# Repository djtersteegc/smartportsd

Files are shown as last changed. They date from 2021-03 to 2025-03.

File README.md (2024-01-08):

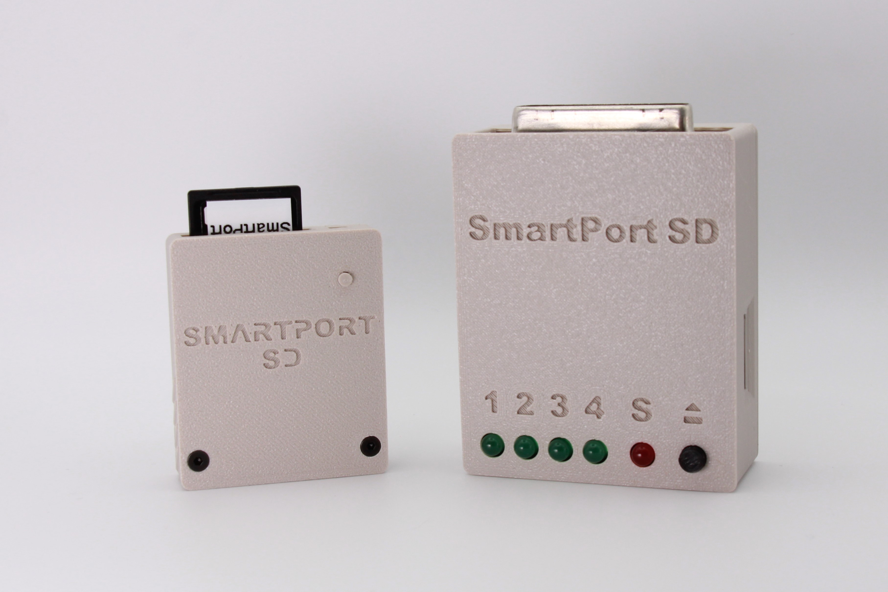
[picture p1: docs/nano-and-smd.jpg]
nano-and-smd


A couple PCB's I've designed to run the SmartportSD FAT code from Katherine Stark (based on the work of Robert Justice and Andrea Ottaviani) allowing you to connect a 32MB ProDOS partition to your SmartPort enabled Apple II (IIc, IIc+, IIgs). If you have a Apple IIe, solutions like a SoftSP card with you Disk II card, or something like Brad Bell's [SmartDiskII](https://github.com/btb/SmartDiskII) card will also allow hookup and usage. Yes, it works with Total Replay.

# SmartportSD Nano Shield

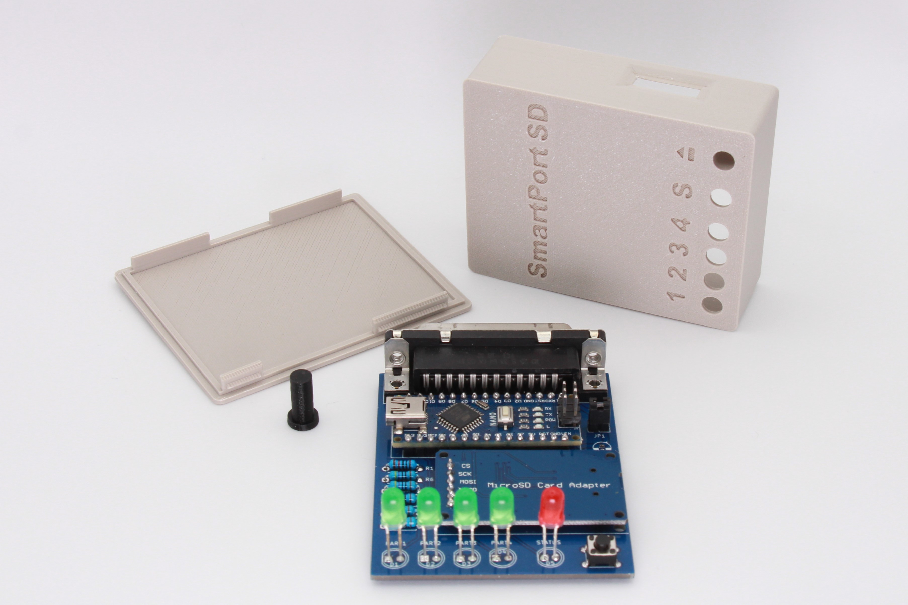
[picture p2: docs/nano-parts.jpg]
nano-parts


This is my original design.  Works best with a Duo Disk cable, but has a header to wire up a custom cable if needed.  All through hold modules, super easy build. I added some additional LED's to indicate which of the four ProDOS partitions is currently loaded.

See the [Nano Shield page](smartportsd-nano-shield/README.md) for BOM and assembly instructions.

# SmartportSD SMD

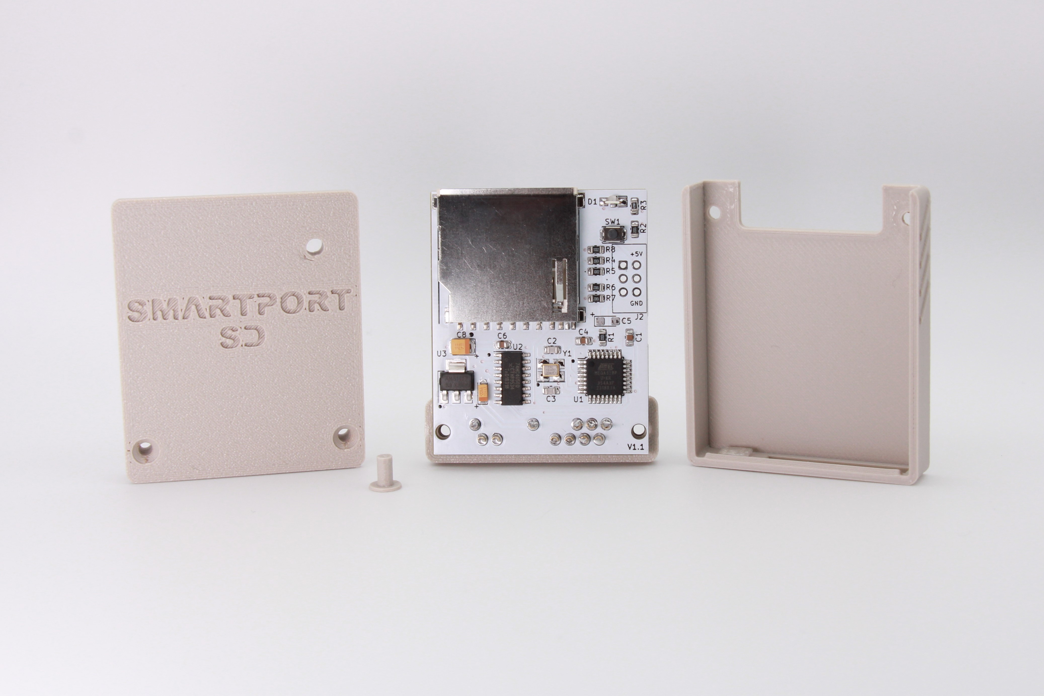
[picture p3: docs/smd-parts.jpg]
smd-parts


This one is a bit more of an advanced build and is based off my [Tapecart SD](https://github.com/djtersteegc/tapecart-sd-vertical) design I did for the Commodore 64. Uses a full size SD card for ease of handling and plugs in directly to the back of an Apple IIc/c+/gs.  There is a lightpipe for the activity LED and the narrow case design allows plenty of clearance for the bulkiest composite video connectors I could find in my collection.

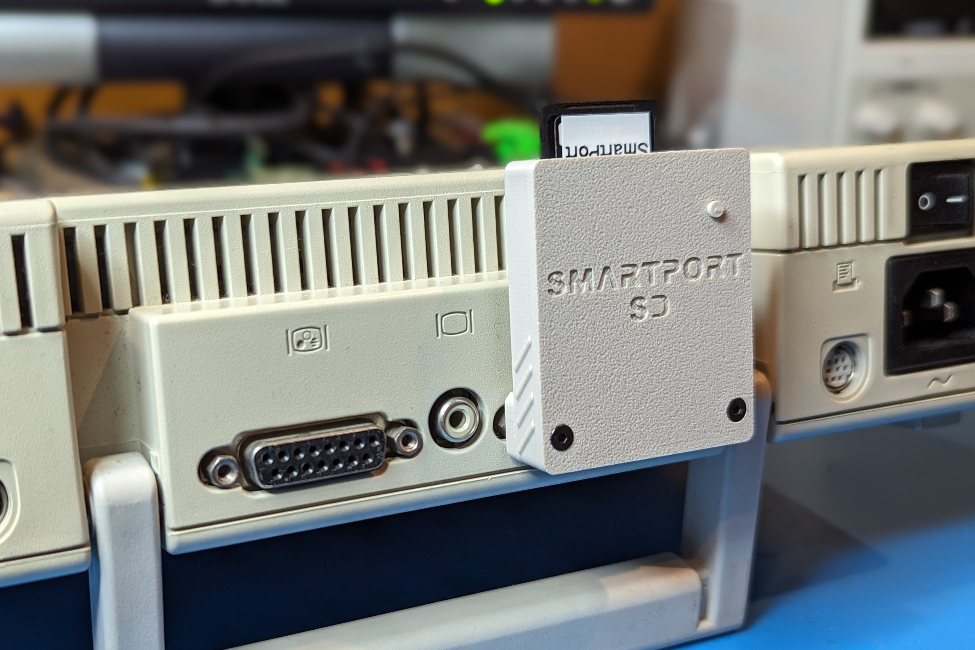
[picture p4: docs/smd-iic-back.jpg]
smd-iic-back


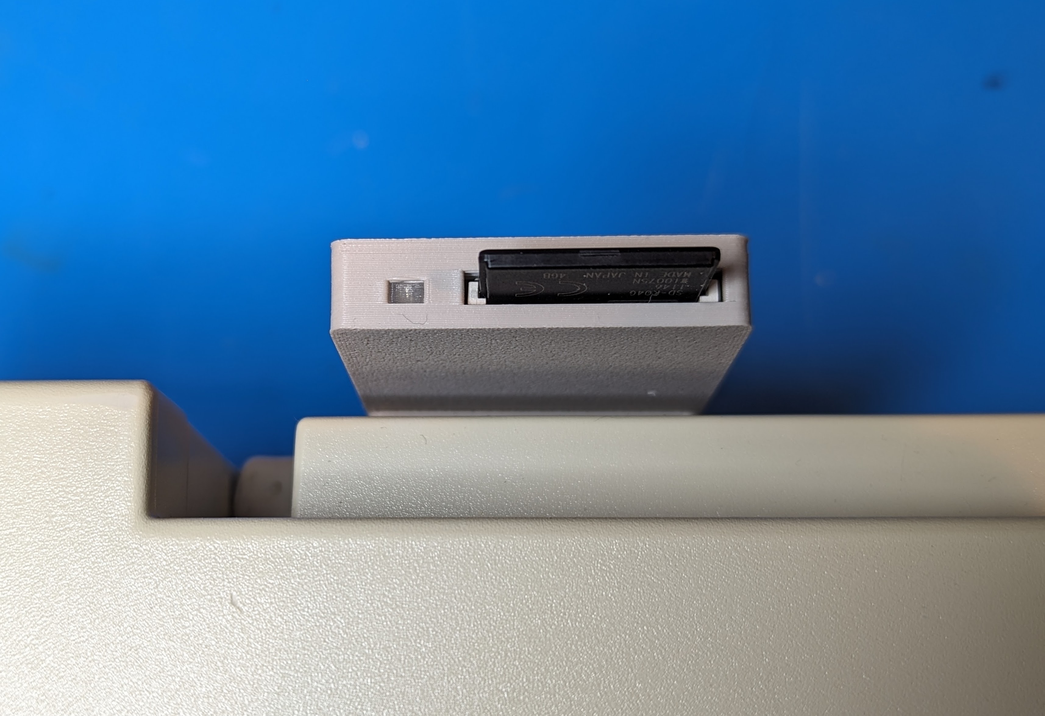
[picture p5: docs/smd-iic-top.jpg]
smd-iic-top


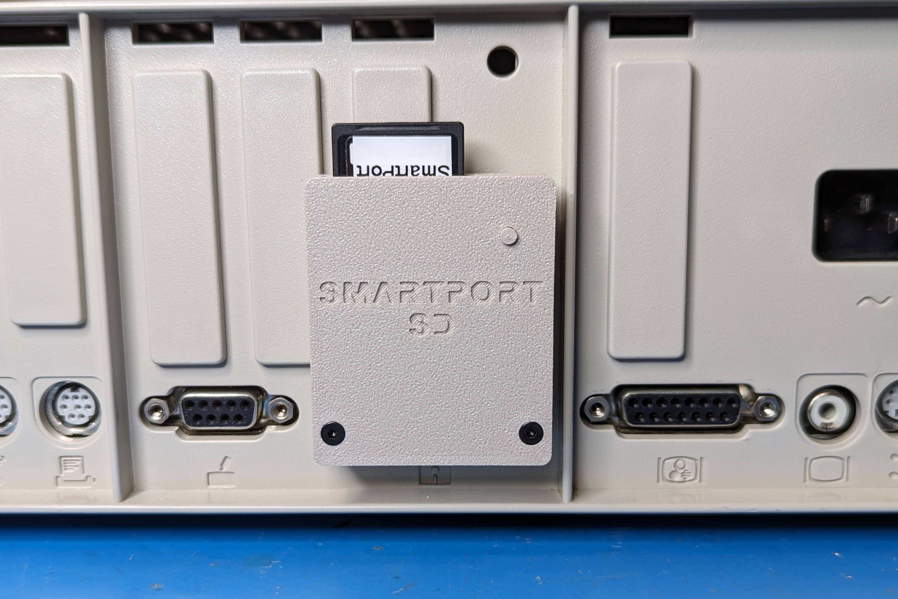
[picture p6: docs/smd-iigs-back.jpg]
smd-iigs-back


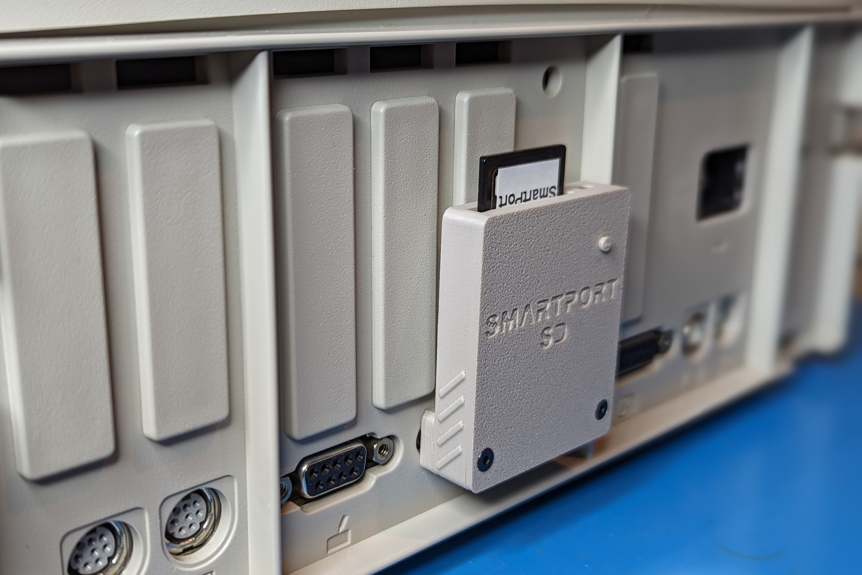
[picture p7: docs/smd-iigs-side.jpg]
smd-iigs-side


See the [SMD page](smartport-smd/README.md) for BOM and assembly instructions.

# Getting a Board

If I have extra PCB's, they will be listed on Tindie.

https://www.tindie.com/products/tersteeg/smartportsd-apple-ii-pcb/

Otherwise, you can download the gerbers and use your favorite fab (JLCPCB, PCBWay, etc.) to make your own batch.

# Acknowledgements

Robert Justice for his original SmartPortCFA project http://www.users.on.net/~rjustice/SmartportCFA/SmartportCFA.htm

Andrea Ottaviani for his Arduino/SD port of Robert's work http://www.users.on.net/~rjustice/SmartportCFA/SmartportSD.htm

Katherine Stark for adding FAT support to Andrea's work to make it easier to manage the partitions on the SD card. https://gitlab.com/nyankat/smartportsd

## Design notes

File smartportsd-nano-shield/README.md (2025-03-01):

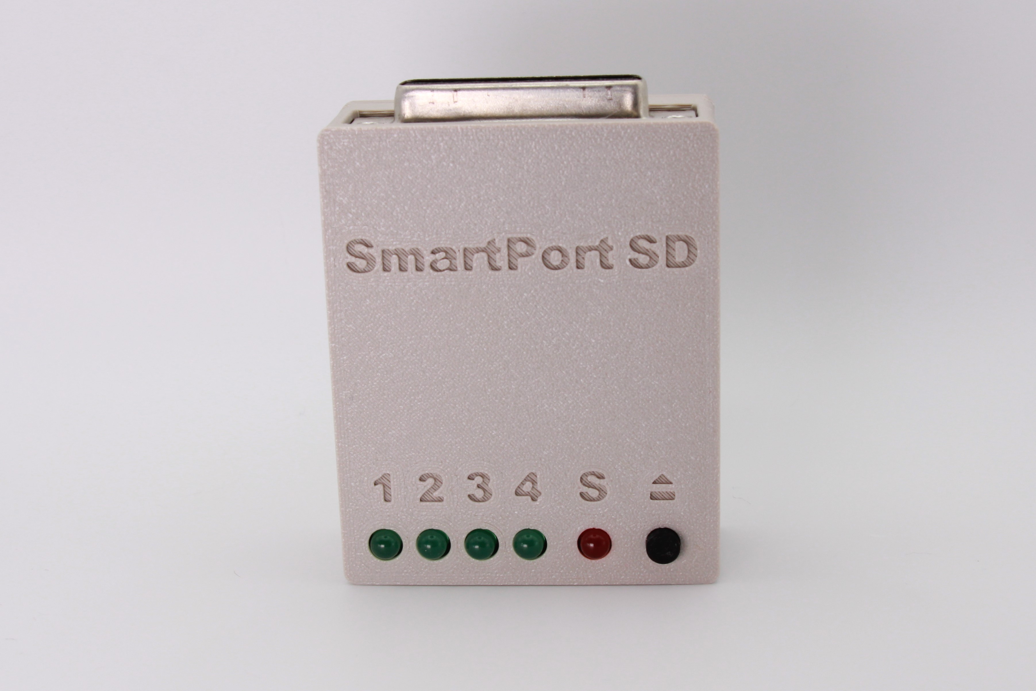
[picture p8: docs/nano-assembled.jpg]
nano-assembled


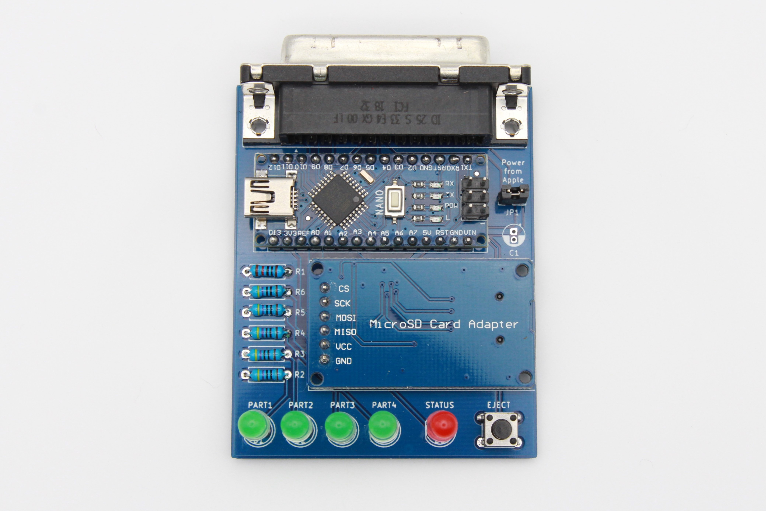
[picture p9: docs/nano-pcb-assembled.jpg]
nano-pcb-assembled


# BOM

All components can be sourced from the usual low-cost China based vendors for a total build cost of around $10. An interactive BOM and parts placement diagram is available.

[Interactive Bill of Materials (BOM)](https://djtersteegc.github.io/smartportsd/ibom-nano-shield-v1.0.html)

### Arduino Nano v3.0

I've had good luck with the ~$2 Chinese clones, but I would suggest flashing it first before soldering to the board.  Sometimes you do get a bad unit, or a unit that hasn't been flashed with the boot loader and requires you flash it yourself via the ICSP headers.

Make sure it's a 16Mhz ATMEGA328P board running at 5V.

### Micro SD Card Connector

This is the common push-push [Micro SD module](https://www.aliexpress.com/item/1873549637.html) with level shifters.  Sometimes it may say "Catalex" (maybe the original designer?) on the back of the PCB.  You will need to remove the pre-soldered right-angle header they all seem to come with so you can mount it upside down on the shield board.

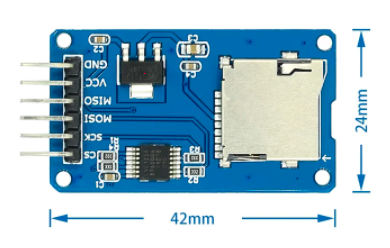
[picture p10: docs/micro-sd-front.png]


### Bulk Capacitor

C1 is a bulk storage capacitor for the 5V rail.  It is optional since the Arduino already has caps on-board, but if you have a marginal SmartPort 5V line or experience other power issues, they could help stabilize the overall board.  Any value between 10uf to 47uf is fine.

### Resistors

Either 1/4W or 1/8W can be used in all locations.

R1 is the pull-down resistor for the eject button.  Anything from 10K to 47K is probably fine here.

R2 through R6 controls the activity and active partition LED brightness. A good calculator is at:

[http://ledcalc.com/](http://ledcalc.com/)

if you want to use something other the 470 ohm spec on the board.  Just don't exceed 20ma.

# Case

STL's and the [DesignSpark Mechanical](https://www.rs-online.com/designspark/mechanical-software) source file for an simple snap fit enclosure are in the **enclosure** directory. Clearances are intentionally a bit tight so nothing rattles, but it prints well on a standard Ender 3 type printer without any post processing needed.

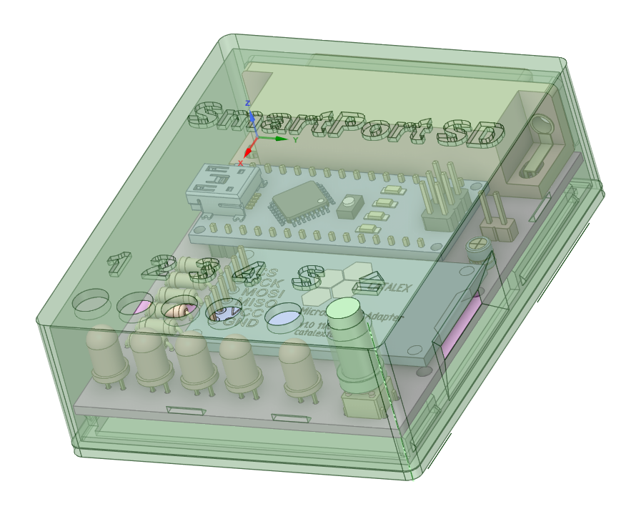
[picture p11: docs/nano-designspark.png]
nano-designspark


# Assembly

If you plan on casing the PCB, print the case out first before the install the LED's you can space them properly.  I use about 2.4mm of reveal with standard 5mm LED's so they are just poking above the surface of the case face.

# Firmware Flashing

Katherine's original repo is at https://gitlab.com/nyankat/smartportsd

I have a fork at https://gitlab.com/tersteeg/smartportsd that adds support for the four LED's in this design that show you the currently active partition.

# Connecting to your Apple II

You have two options here.  If you are lucky enough to have a DB19 to DB25 DuoDisk Drive cable, you can simply solder on a female DB25 jack and you're good to go.

The IDC-20 pin mapping can be used with the various DB19 to IDC-20 adapter available, like the one from the Fujinet project, https://github.com/FujiNetWIFI/fujinet-hardware/tree/master/AppleII/DB-19M-Adapter-Male-Rev1

Or you can wire up your own cable using the 2.54mm 9p header J2. The pinout is as follows:

| SmartPort | DB19 pin | IDC-20 pin | J2 pin | DB25 pin |
| --- | --- | --- | --- | --- |
| RDDATA | 18 | 16 | 1 | 3 |
| PH0 | 11 | 2 | 2 | 15 |
| PH1 | 12 | 4 | 3 | 16 |
| PH2 | 13 | 6 | 4 | 17 |
| PH3 | 14 | 8 | 5 | 18 |
| WRDATA | 19 | 18 | 6 | 6 |
| +5V | 6 | 11 | 7 | 7 |
| GND | 1 | 1 | 8 | 2 |
| WRPROT | 10 | 20 | 9 | 12 |

# Usage

If you wish to power your board from the 5V SmartPort line, simply install and close jumper JP1.  Be warned there is no protection on the board from back feeding voltage into the Apple host computer if you also power the Arduino via the USB connector, so only close this jumper when not using another power source on the Arduino.

# Getting a Board

If I have extra PCB's, they will be listed on Tindie.

https://www.tindie.com/products/tersteeg/smartportsd-apple-ii-pcb/

Otherwise you can download the Gerbers and use your favorite fab (JLCPCB, PCBWay, etc.) to make your own batch.  It's a standard two layer, 1oz copper board with dimensions of 70mm x 56mm.

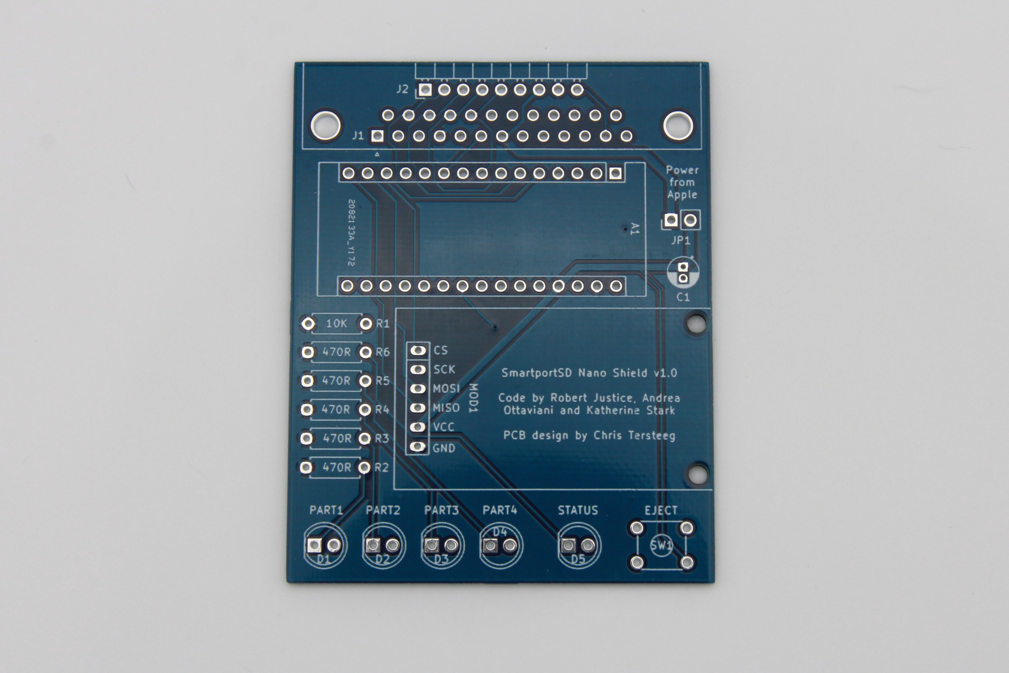
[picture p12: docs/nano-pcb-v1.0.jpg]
nano-pcb-v1.0


# Hardware Revisions

### Version 1.0

Tested and working.

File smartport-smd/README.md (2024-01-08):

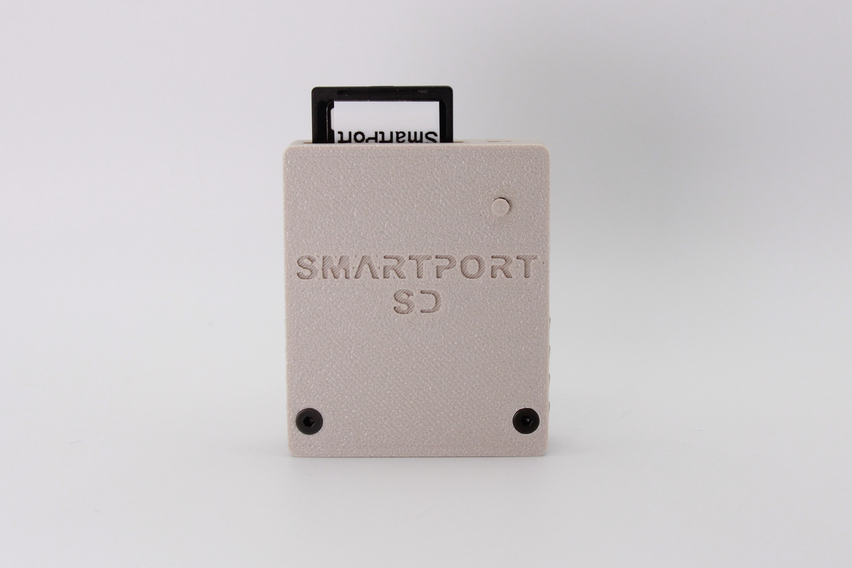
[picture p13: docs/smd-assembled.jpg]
smd-assembled


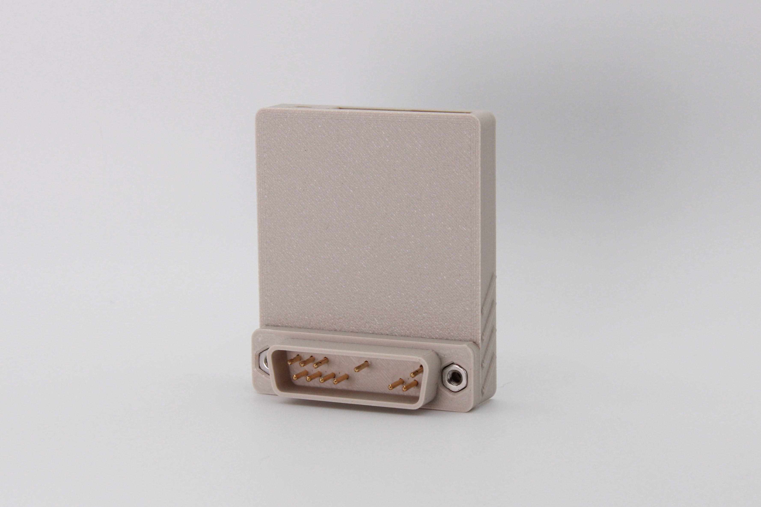
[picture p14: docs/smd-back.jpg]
smd-back


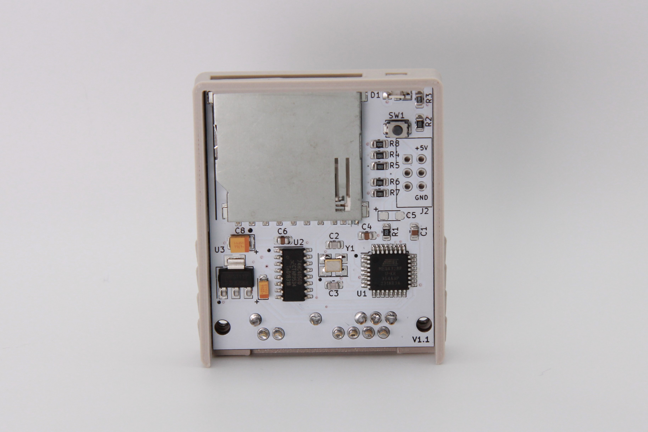
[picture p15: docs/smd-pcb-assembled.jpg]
smd-pcb-assembled


# BOM

There's an interactive BOM [here](https://djtersteegc.github.io/smartportsd/ibom-smd-v1.1.html), and CSV version with footprint info [here](https://djtersteegc.github.io/smartportsd/bom-smd-v1.1.csv). The interactive one is super useful when placing the SMD components.

C5 is an optional bulk capacitor for the 5V power rail near the MCU.  In my experience building these it is not needed.

The SD card connector is commonly available from several different Chinese suppliers and often called "long body", "non popping", or "push pull" on AliExpress or eBay.

https://www.aliexpress.us/item/3256805779248826.html

Here's some links on LCSC.

https://www.lcsc.com/product-detail/SD-Card-Connectors_Hanbo-Electronic-SD-112_C961673.html

https://www.lcsc.com/product-detail/SD-Card-Connectors_XUNPU-SD-102_C266602.html

https://www.lcsc.com/product-detail/SD-Card-Connectors_Megastar-ZX-SD-282-8Y_C7419835.html

It should also cross with a Wurth 693063010911 or AMP GSD090012SEU if you want something domestically.

The pins for the DB19 connector can be purchased from this seller on AliExpress,  https://www.aliexpress.us/item/3256802431271655.html Ideally I would have used the "PCB Plug" model if they stocked them which are similar to the TE/AMP 5-745287-4 model mozzwald used on the [FujiApple DB19 to IDC20 adapters](https://github.com/FujiNetWIFI/fujinet-hardware/tree/master/AppleII/DB-19M-Adapter), but these are much more cost effective and work just as well once assembled.

# Case

The case was created in DesignSpark and the design file is available if you would like to modify it further.

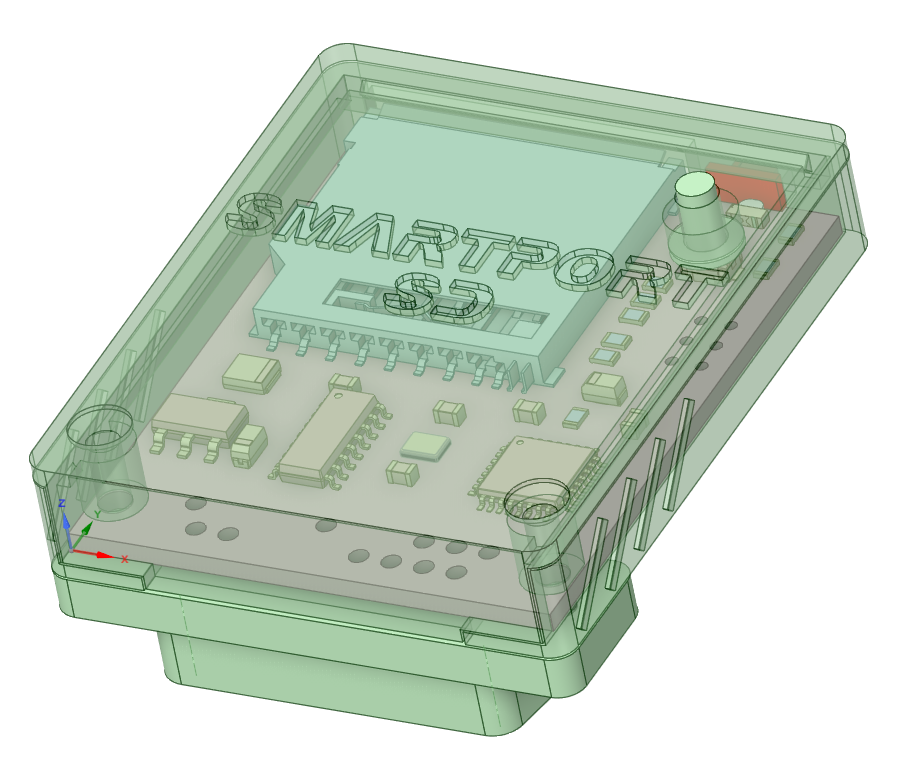
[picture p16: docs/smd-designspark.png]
smd-designspark


There is a single light pipe that should be printed in transparent material, or you can just leave it off completely. The case is designed to be printed at 0.2mm layer heights and assembled with two M2.5x14mm screws through the connector body and two M2.5 nuts pushed into either the handle or lid.

# Assembly

Assemble all the SMD components.  I use solder paste hand applied with a pneumatic dispenser and then finish on a hot plate. But you can also hand solder, use hot air, or even order a stencil for paste application and use a proper reflow oven. I use a red LED for the activity indicator. Make sure to observe polarity with the green stripe on the LED to the right matching the white stripe on the PCB silkscreen.

For the ATMEGA328P chip I did use part of stencil I had from a previous project with the same footprint, or you can buy one from [Amazon](https://www.amazon.com/Proto-Advantage-PA0091-S-TQFP-32-LQFP-32-Stainless/dp/B09886QDY9/ref=sr_1_3). Cheaper than ordering a whole stencil from somewhere like JLCPCB once you factor in shipping costs.

Do NOT install the 2x3 ICSP pin header at J2.  I would recommend flashing the firmware at this point to do basic checks since it's easier to do board rework before you install the DB19 pins.

To install the connector, first take your printed DB19 shell and use a 1.0mm and 2.0mm drill bit to properly size the holes.  I use a cut down DB25 connector to hold the pins straight while soldering. It also makes a nice way to hold everything in a vise.

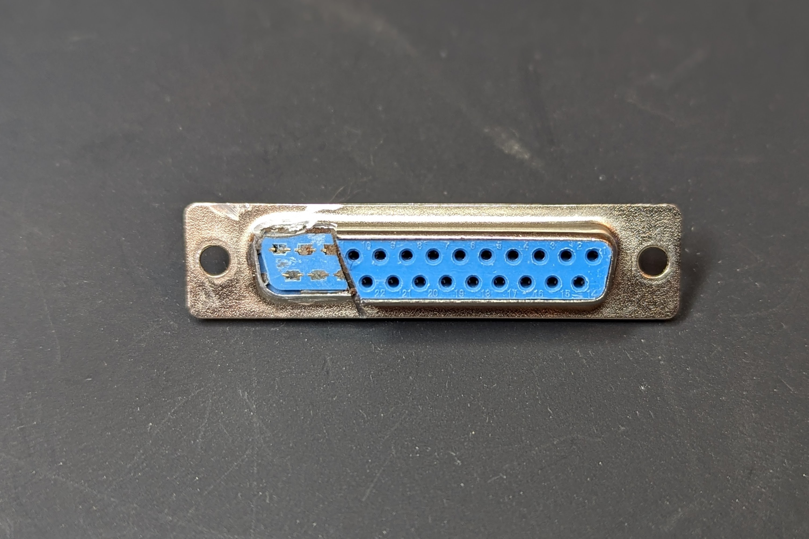
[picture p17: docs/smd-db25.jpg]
smd-db25


Insert the pins and case shell through the case back and assemble with short M2.5 screws.  Tighten the screws gently so you can still slide out the case in the future if needed and then solder the pins. Ensure the tops of all the pins are even and the bottom of the solder cup on the pins should be close to even with the PCB.

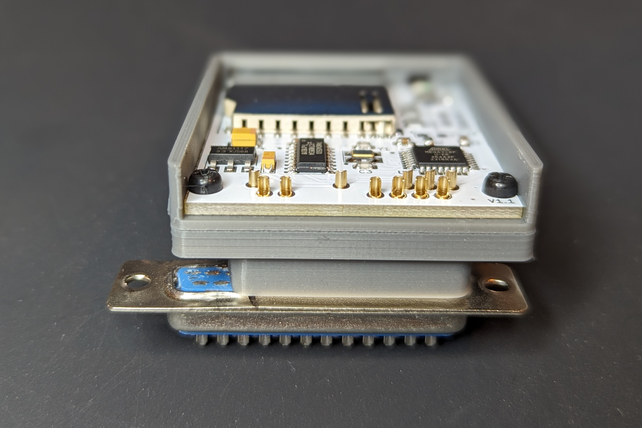
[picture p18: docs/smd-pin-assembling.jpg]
smd-pin-assembling


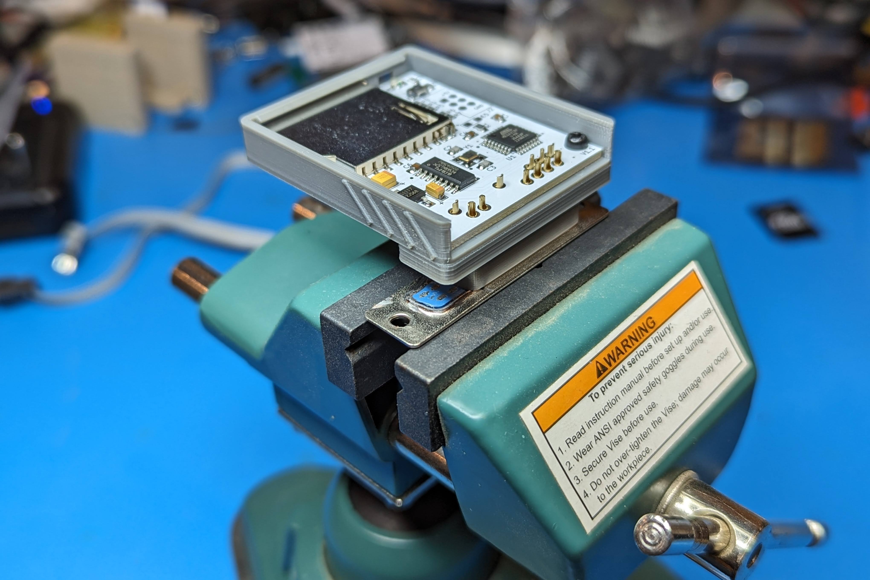
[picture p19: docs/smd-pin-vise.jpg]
smd-pin-vise


When complete it should look something like this when slid out of the case.

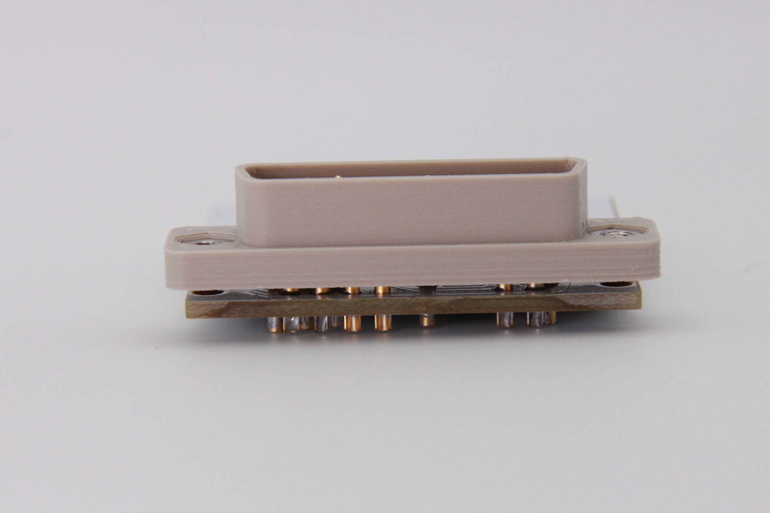
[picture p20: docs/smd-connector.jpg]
smd-connector


Press the light pipe into the LED opening with the lip side facing up and then slide the board in. If you can't slide the PCB under the light pipe, it is installed upside down.  The side mounted LED's should keep the light pipe from falling out, even if it isn't a tight friction fit in the openings.

# Firmware Flashing

The ATmega328P is the same used on an Arduino Uno/Nano/Micro, but lacks the necessary bootloader firmware and serial interfaces to flash via the Arduino IDE or programs like XLoader. You could program the chip before installing it with something like a [TL866/T48](TL866/T48) and a [TQFP32 to DIP 32 adapter](https://www.aliexpress.us/item/2251832227450089.html), but I prefer to just use a cheap [UBSASP](https://www.aliexpress.us/item/2251832600419163.html) and [avrdude](https://github.com/avrdudes/avrdude). Make sure you get a 10 pin to 8 pin adapter with the USBASP if it isn't natively an 8 pin model.

Since you didn't solder the 2x3 pin header on the ICSP port J2, you will need to hold the header pins at an angle in the holes to make contact while you run avrdude.  If you're feeling fancy, you could spring for a [2x3 double row 2.54mm test clip](https://www.aliexpress.us/item/3256805646654844.html) or [handheld pogo pin probe](https://www.aliexpress.us/item/3256805545980544.html).  The cheap angle method works fine for me.

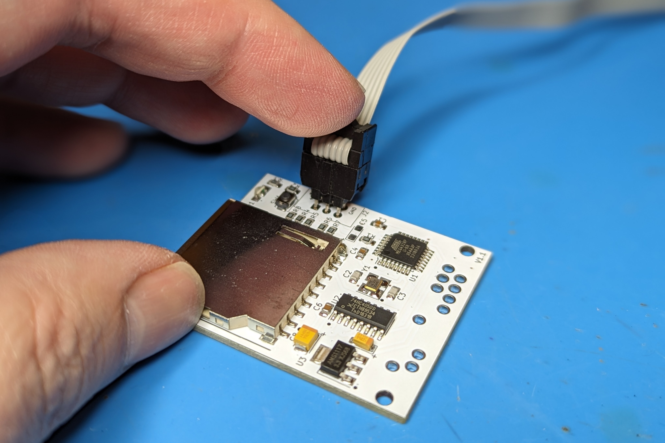
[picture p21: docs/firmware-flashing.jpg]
firmware-flashing


Since this model doesn't have the extra LED's to show the active partition, the firmware used is Katherine's standard version from https://gitlab.com/nyankat/smartportsd.  

In my [firmware](firmware) directory there are couple of Windows scripts and a precompiled version of the SmartportSD firmware.

First you to need to setup your ATMega328p with the correct fuse setting so it uses the external 16 MHz crystal, same as an Arduino board. **burn-328p-fuses.cmd** executes the following:

`avrdude -c usbasp -p m328p -B 125kHz -U lfuse:w:0xFF:m -U hfuse:w:0xDE:m -U efuse:w:0x05:m`

Next flash SmartportSD-1.15.ino.with_bootloader.standard.hex with **flash-smartportsd.cmd** that executes:

`avrdude -c usbasp -p m328p -u -U flash:w:SmartportSD-1.15.ino.with_bootloader.standard.hex`

Plug into your Apple II and enjoy! 

# Getting a Board

If you are in the US, PCB's are available from my Tindie store, https://www.tindie.com/products/tersteeg/smartportsd-apple-ii-pcb/

Otherwise, you can grab the [gerbers](gerbers) and order from your favorite PCB fab.

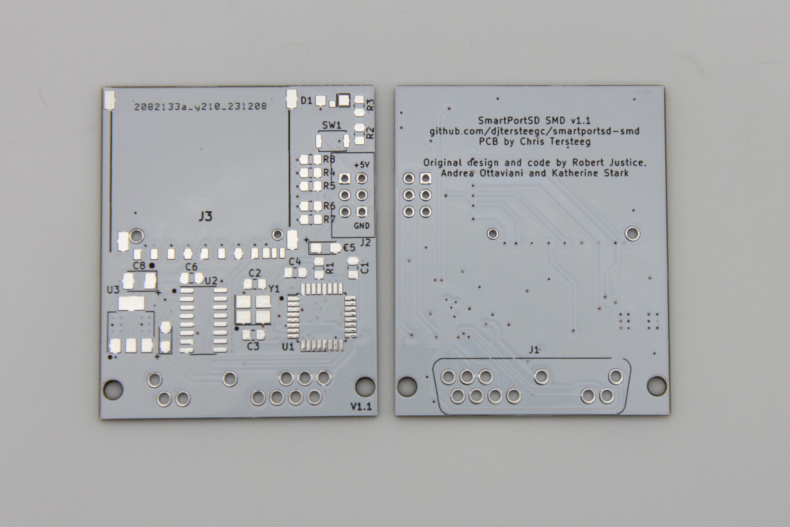
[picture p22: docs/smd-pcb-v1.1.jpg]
smd-pcb-v1.1


# PCB Revisions

### Version 1.0

Worked but since it was pertty much a 1:1 copy of my TapecartSD base PCB, was just a little to wide to clear the composite video connector on an Apple IIc once cased.

### Versions 1.1 (Current)

Board was narrowed to allow needed clearance on IIc/c+ models.

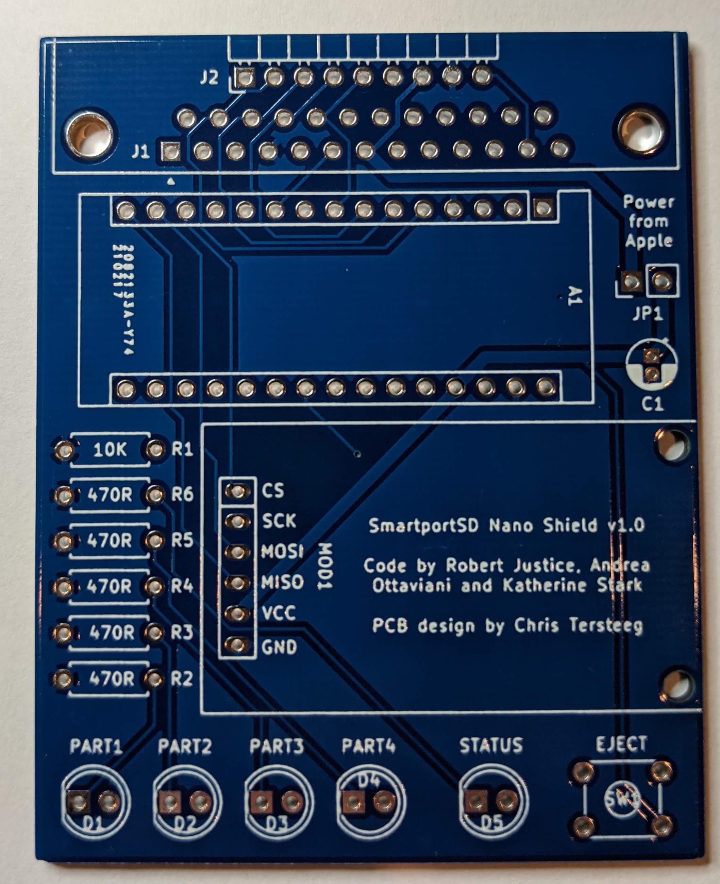
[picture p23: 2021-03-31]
docs/pcb-v1.0.jpg

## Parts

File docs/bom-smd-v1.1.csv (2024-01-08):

# | Reference | Qty | Value | Footprint | DNP
1 | C1, C4, C6 | 3 | 0.1uf | Capacitor_SMD:C_0805_2012Metric_Pad1.18x1.45mm_HandSolder
2 | C2, C3 | 2 | 18pf | Capacitor_SMD:C_0805_2012Metric_Pad1.18x1.45mm_HandSolder
3 | C5, C7 | 2 | 22uf 10V | Capacitor_Tantalum_SMD:CP_EIA-3216-18_Kemet-A_Pad1.58x1.35mm_HandSolder
4 | C8 | 1 | 47uf 10V | Capacitor_Tantalum_SMD:CP_EIA-3528-12_Kemet-T_Pad1.50x2.35mm_HandSolder
5 | D1 | 1 | LED | Tersteeg:1204 Side Emitting LED
6 | J1 | 1 | DB19_Plug | Tersteeg:DSUB-19_Male_Vertical_P2.77x2.84mm_Narrow_MountingHoles
7 | J2 | 1 | ICSP | Connector_IDC:IDC-Header_2x03_P2.54mm_Vertical
8 | J3 | 1 | SD_Card_Push_Pull | TE SD Card 2041021-3:2041021-3_2
9 | R1, R2, R4, R5, R6, R7, R8 | 7 | 10K | Resistor_SMD:R_0805_2012Metric_Pad1.20x1.40mm_HandSolder
10 | R3 | 1 | 470R | Resistor_SMD:R_0805_2012Metric_Pad1.20x1.40mm_HandSolder
11 | SW1 | 1 | SW_SPST | Button_Switch_SMD:SW_Push_SPST_NO_Alps_SKRK
12 | U1 | 1 | ATmega328P-A | Package_QFP:TQFP-32_7x7mm_P0.8mm
13 | U2 | 1 | 4050 | Package_SO:SOIC-16_3.9x9.9mm_P1.27mm
14 | U3 | 1 | AMS1117-3.3 | Package_TO_SOT_SMD:SOT-223-3_TabPin2
15 | Y1 | 1 | 16MHz | Crystal:Crystal_SMD_3225-4Pin_3.2x2.5mm_HandSoldering

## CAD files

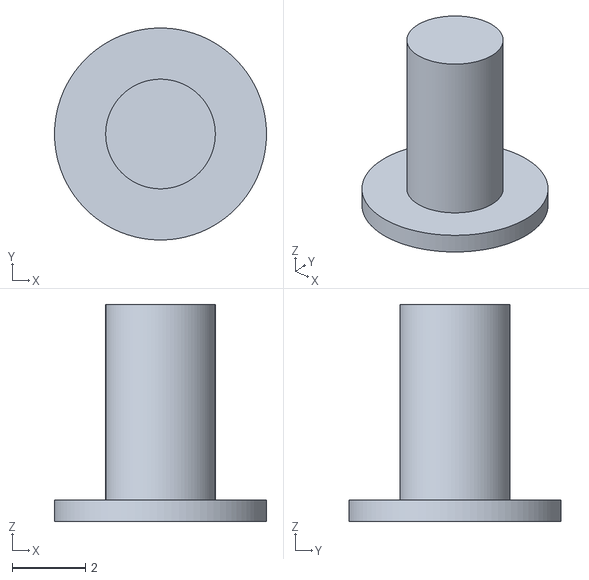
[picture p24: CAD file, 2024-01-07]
smartport-smd/3D/STL/smartport-smd-button.stl
5.80 x 5.80 x 5.95

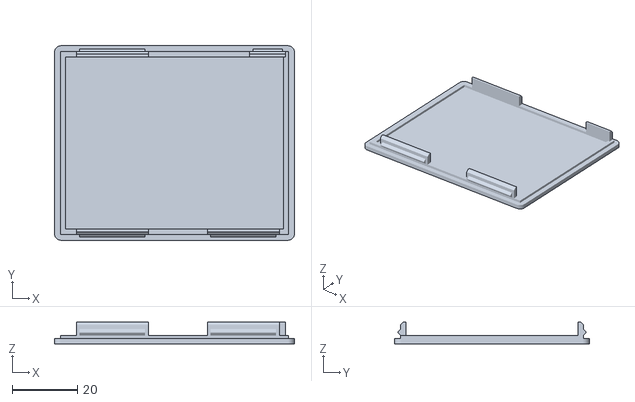
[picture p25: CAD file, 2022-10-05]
smartportsd-nano-shield/enclosure/smartportsd-nano-shield-lid.stl
73.5 x 59.6 x 6.60

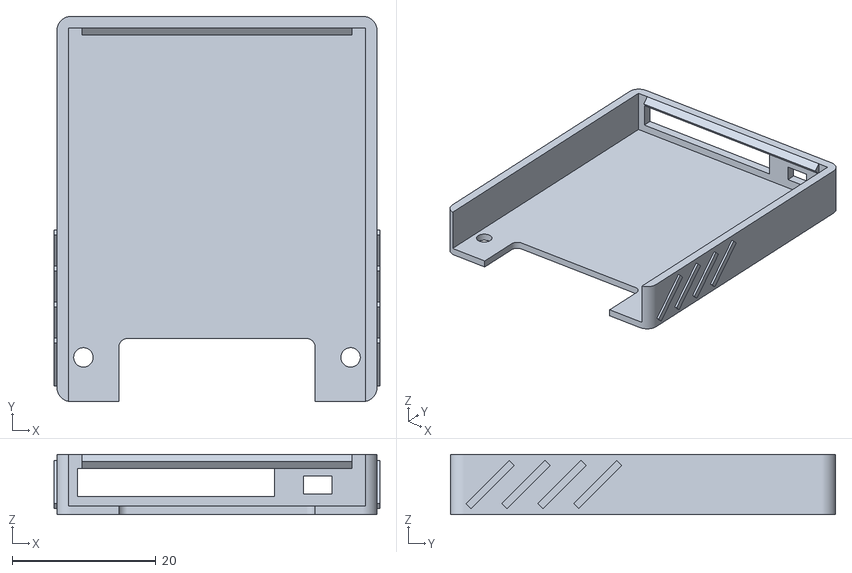
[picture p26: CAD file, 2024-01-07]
smartport-smd/3D/STL/smartport-smd-body.stl
45.4 x 53.6 x 8.40

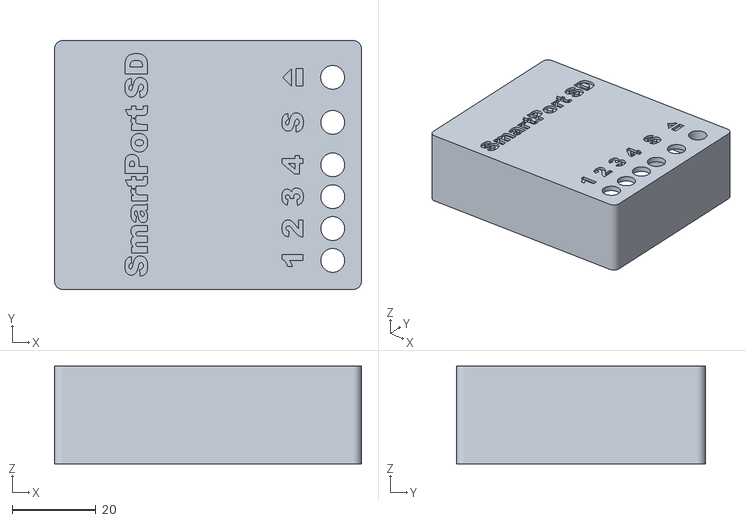
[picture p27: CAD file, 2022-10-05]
smartportsd-nano-shield/enclosure/smartportsd-nano-shield-body.stl
73.5 x 59.6 x 23.4

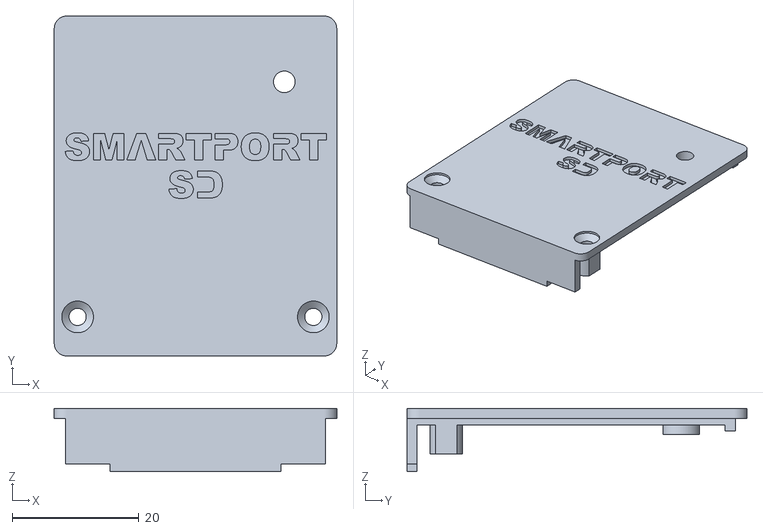
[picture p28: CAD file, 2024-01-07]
smartport-smd/3D/STL/smartport-smd-lid.stl
44.6 x 53.6 x 10.0

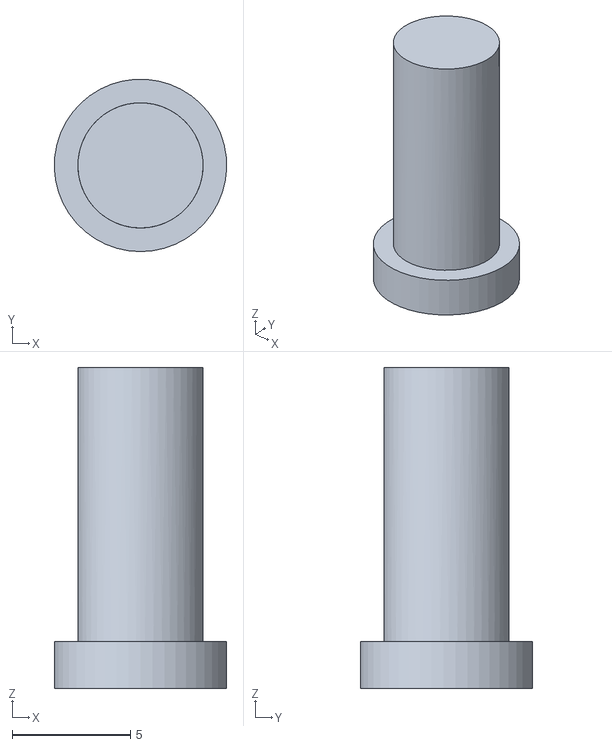
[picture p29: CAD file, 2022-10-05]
smartportsd-nano-shield/enclosure/smartportsd-nano-shield-button.stl
7.30 x 7.29 x 13.6

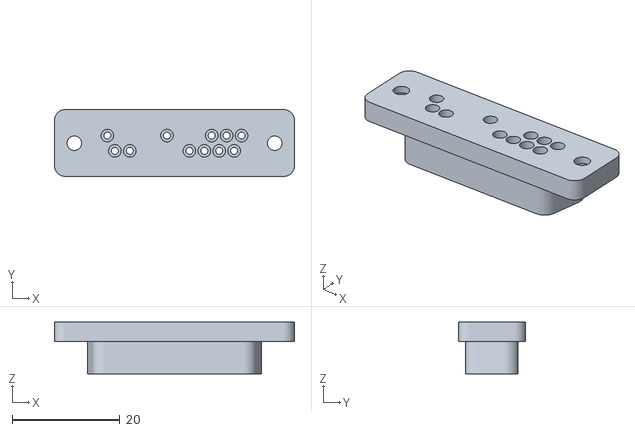
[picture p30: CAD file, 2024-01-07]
smartport-smd/3D/STL/smartport-smd-db19.stl
44.6 x 12.4 x 9.60

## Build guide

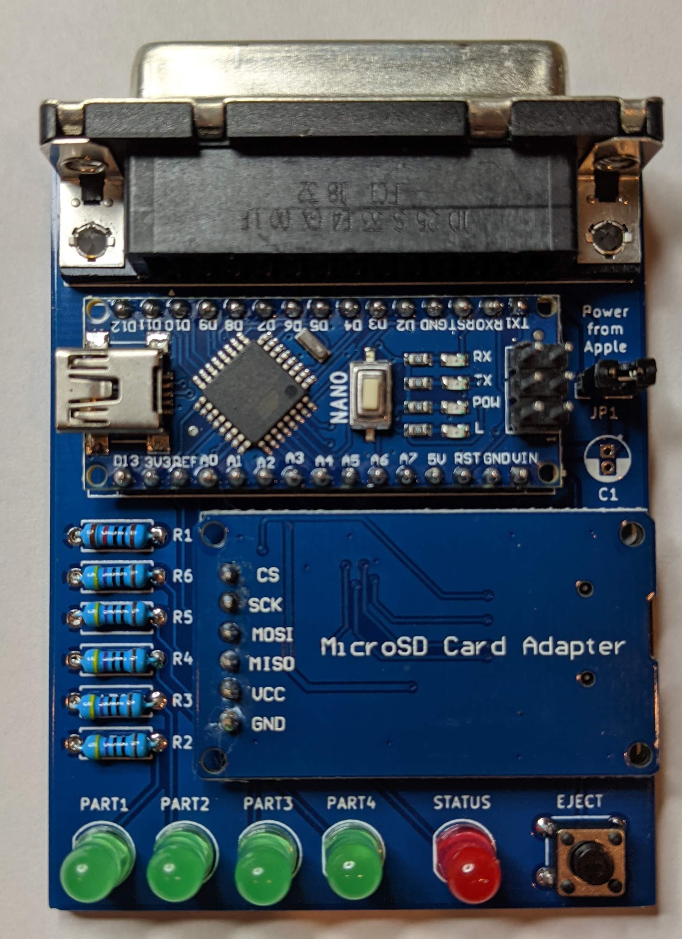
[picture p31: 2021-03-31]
docs/assembled.jpg

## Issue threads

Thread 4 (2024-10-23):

Doesn't seem to build using the latest version of the sdfat arudino library

Monsjakon, 2024-10-23:

hexbus, 2025-02-27:
Yep, you need to backlevel it per here:  https://tinkerdifferent.com/threads/smartportsd-lets-build-it.454/post-34114

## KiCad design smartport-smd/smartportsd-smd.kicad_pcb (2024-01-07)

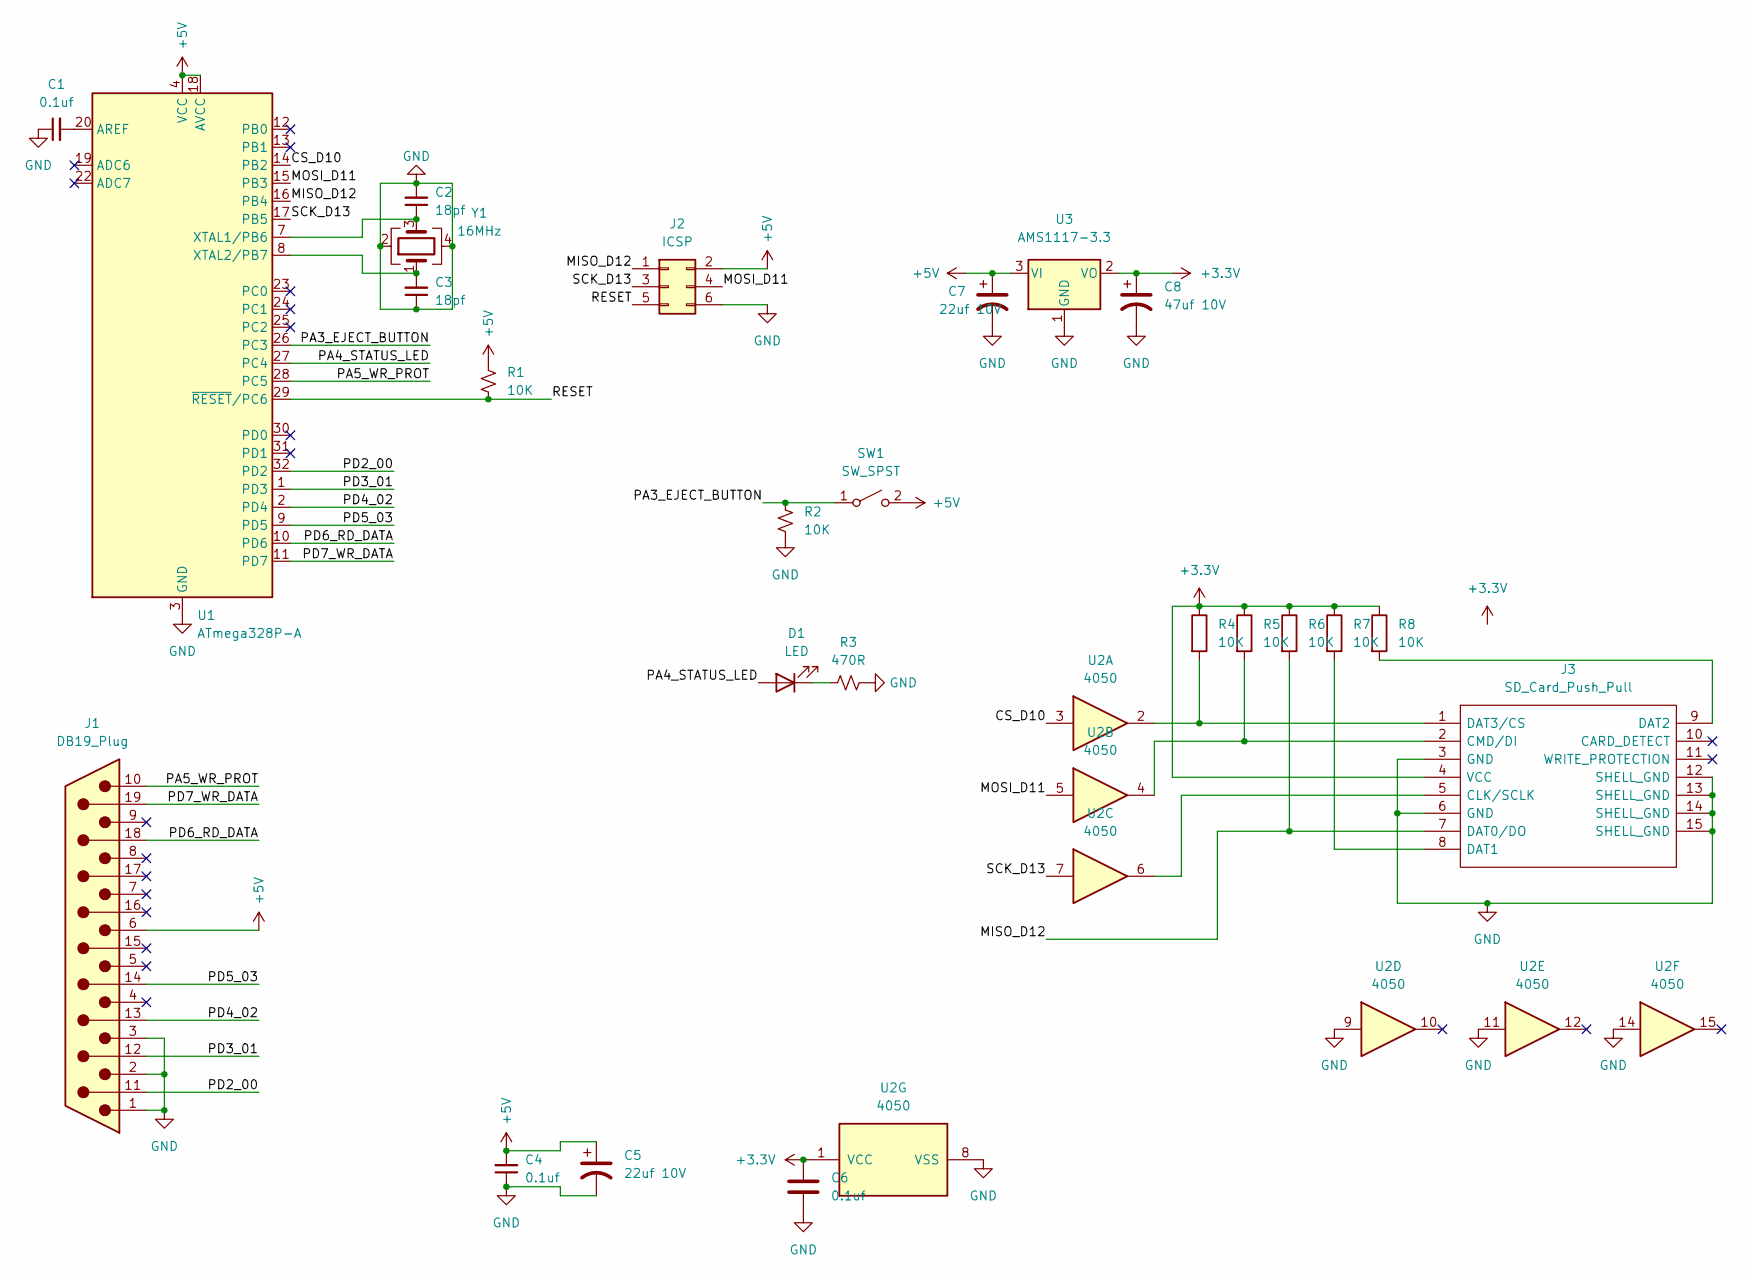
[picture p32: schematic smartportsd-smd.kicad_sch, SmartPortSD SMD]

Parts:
C1, C4, C6: 0.1uf; C_0805_2012Metric_Pad1.18x1.45mm_HandSolder
C2, C3: 18pf; C_0805_2012Metric_Pad1.18x1.45mm_HandSolder
C5, C7: 22uf 10V; CP_EIA-3216-18_Kemet-A_Pad1.58x1.35mm_HandSolder
C8: 47uf 10V; CP_EIA-3528-12_Kemet-T_Pad1.50x2.35mm_HandSolder
D1: LED; 1204 Side Emitting LED
J1: DB19_Plug; DSUB-19_Male_Vertical_P2.77x2.84mm_Narrow_MountingHoles
J2: ICSP; IDC-Header_2x03_P2.54mm_Vertical
J3: SD_Card_Push_Pull; 2041021-3_2; Manufacturer_Part_Number 2041021-3; Mouser Part Number 571-2041021-3
R1, R2, R4, R5, R6, R7, R8: 10K; R_0805_2012Metric_Pad1.20x1.40mm_HandSolder
R3: 470R; R_0805_2012Metric_Pad1.20x1.40mm_HandSolder
SW1: SW_SPST; SW_Push_SPST_NO_Alps_SKRK
U1: ATmega328P-A; TQFP-32_7x7mm_P0.8mm
U2: 4050; SOIC-16_3.9x9.9mm_P1.27mm
U3: AMS1117-3.3; SOT-223-3_TabPin2
Y1: 16MHz; Crystal_SMD_3225-4Pin_3.2x2.5mm_HandSoldering

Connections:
+3.3V: C6.2, C8.1, J3.4 (VCC), R4.1, R5.1, R6.1, R7.1, R8.1, U2.1 (VCC), U3.2 (VO)
+5V: C4.2, C5.1, C7.1, J1.6, J2.2, R1.1, SW1.2 (B), U1.4 (VCC), U1.6 (VCC), U1.18 (AVCC), U3.3 (VI)
/CS_D10: U1.14 (PB2), U2.3
/MISO_D12: J2.1, J3.7 (DAT0/DO), R6.2, U1.16 (PB4)
/MOSI_D11: J2.4, U1.15 (PB3), U2.5
/PA3_EJECT_BUTTON: R2.1, SW1.1 (A), U1.26 (PC3)
/PA4_STATUS_LED: D1.2 (A), U1.27 (PC4)
/PA5_WR_PROT: J1.10, U1.28 (PC5)
/PD2_00: J1.11, U1.32 (PD2)
/PD3_01: J1.12, U1.1 (PD3)
/PD4_02: J1.13, U1.2 (PD4)
/PD5_03: J1.14, U1.9 (PD5)
/PD6_RD_DATA: J1.18, U1.10 (PD6)
/PD7_WR_DATA: J1.19, U1.11 (PD7)
/RESET: J2.5, R1.2, U1.29 (~RESET/PC6)
/SCK_D13: J2.3, U1.17 (PB5), U2.7
GND: C1.1, C2.2, C3.1, C4.1, C5.2, C6.1, C7.2, C8.2, J1.1, J1.2, J1.3, J2.6, J3.3 (GND), J3.6 (GND), J3.12 (SHELL_GND), J3.13 (SHELL_GND), J3.14 (SHELL_GND), J3.15 (SHELL_GND), R2.2, R3.2, U1.3 (GND), U1.5 (GND), U1.21 (GND), U2.8 (VSS), U2.9, U2.11, U2.14, U3.1 (GND), Y1.2, Y1.4
unnamed: D1.1 (K), R3.1
unnamed: J3.5 (CLK/SCLK), U2.6
unnamed: J3.2 (CMD/DI), R5.2, U2.4
unnamed: J3.8 (DAT1), R7.2
unnamed: J3.9 (DAT2), R8.2
unnamed: J3.1 (DAT3/CS), R4.2, U2.2
unnamed: C1.2, U1.20 (AREF)
unnamed: C2.1, U1.7 (XTAL1/PB6), Y1.3
unnamed: C3.2, U1.8 (XTAL2/PB7), Y1.1

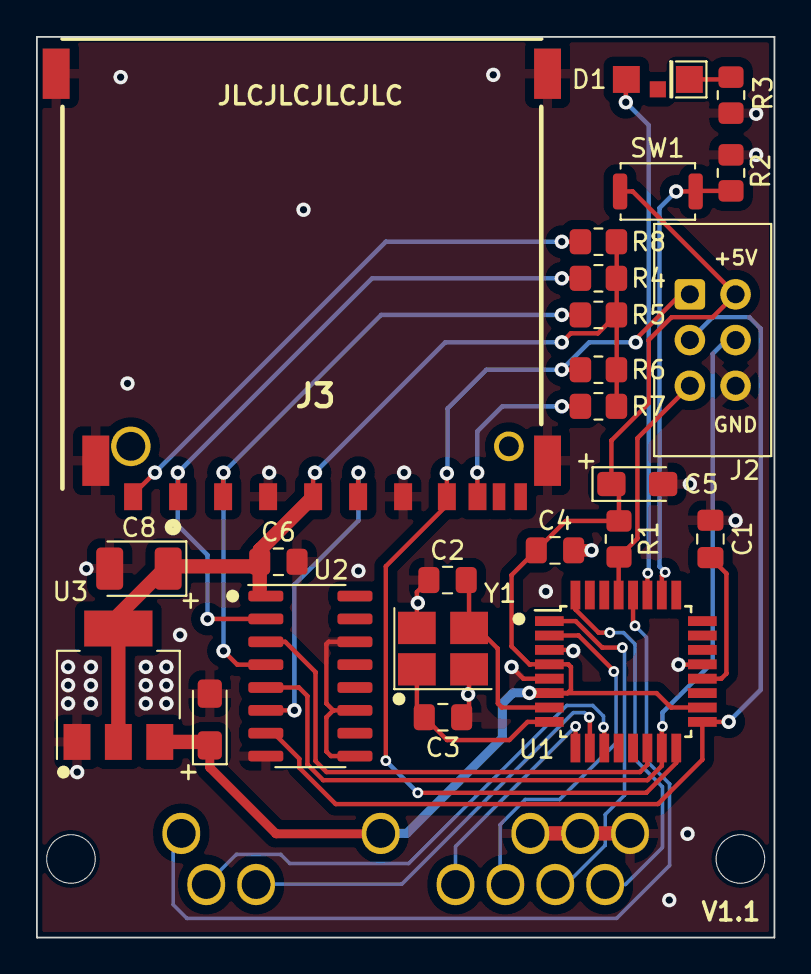
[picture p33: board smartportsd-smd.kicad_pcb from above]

Board: 2 copper layers, 41.0 x 50.0 mm, 25 parts (1 on the bottom side), 26 nets.

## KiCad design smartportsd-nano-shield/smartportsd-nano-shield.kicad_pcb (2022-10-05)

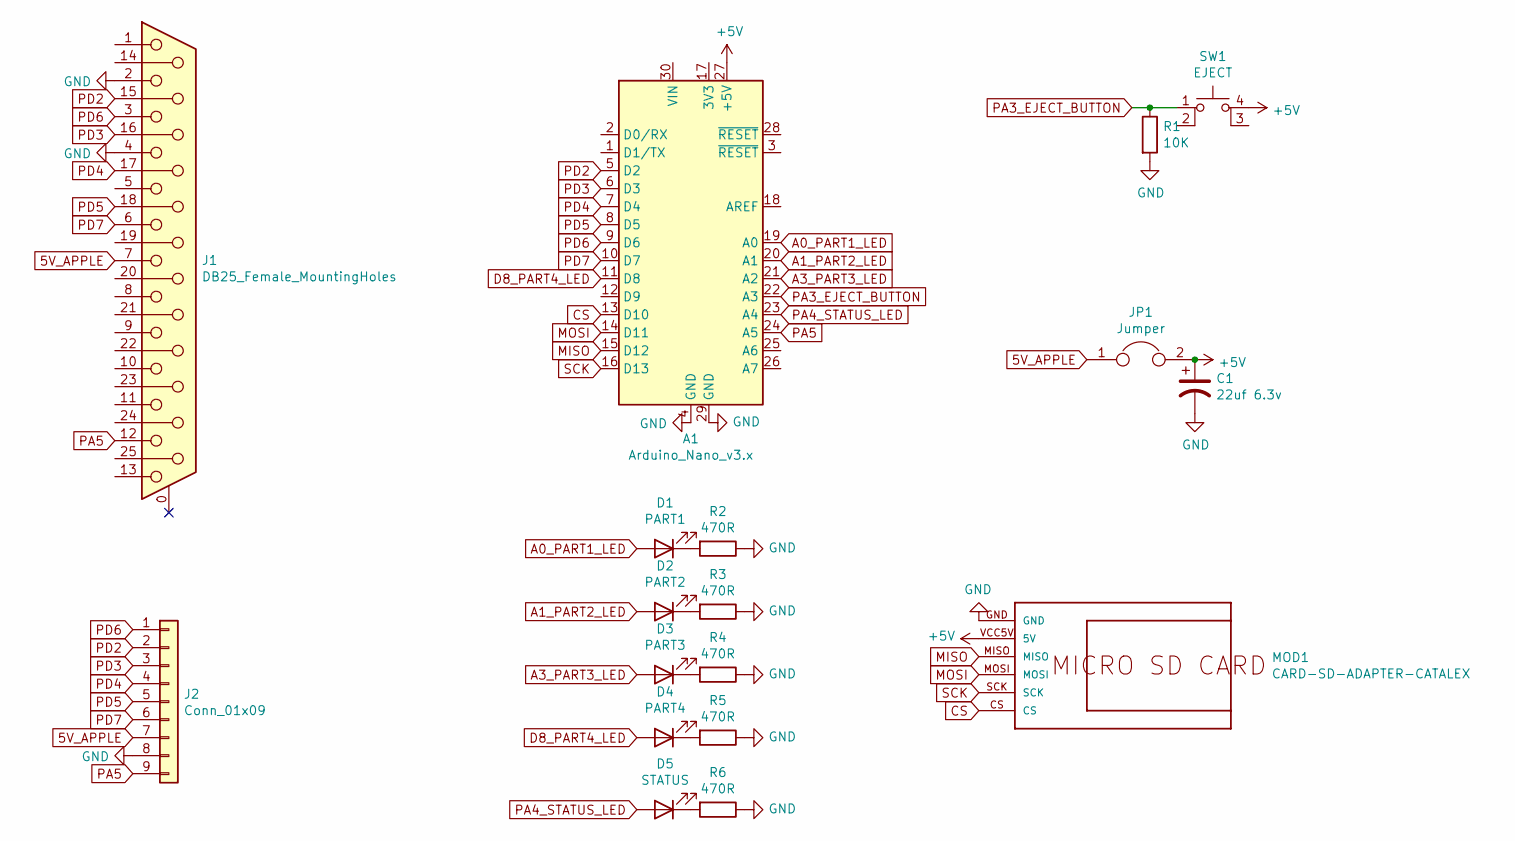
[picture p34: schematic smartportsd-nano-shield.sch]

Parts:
A1: Arduino_Nano_v3.x; Arduino_Nano
C1: 22uf 6.3v; CP_Radial_D4.0mm_P1.50mm
D1: PART1; LED_D5.0mm
D2: PART2; LED_D5.0mm
D3: PART3; LED_D5.0mm
D4: PART4; LED_D5.0mm
D5: STATUS; LED_D5.0mm
J1: DB25_Female_MountingHoles; DSUB-25_Female_Horizontal_P2.77x2.84mm_EdgePinOffset7.70mm_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
J2: Conn_01x09; PinHeader_1x09_P2.54mm_Horizontal
JP1: Jumper; PinHeader_1x02_P2.54mm_Vertical
MOD1: CARD-SD-ADAPTER-CATALEX; Catalex-MicroSD-Card-Down
R1: 10K; R_Axial_DIN0207_L6.3mm_D2.5mm_P7.62mm_Horizontal
R2, R3, R4, R5, R6: 470R; R_Axial_DIN0207_L6.3mm_D2.5mm_P7.62mm_Horizontal
SW1: EJECT; SW_TH_Tactile_Omron_B3F-10xx

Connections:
5V_APPLE: J1.7, J2.7, JP1.1
+5V: A1.27 (+5V), C1.1, JP1.2, MOD1.VCC5V (5V), SW1.4 (A)
A0_PART1_LED: A1.19 (A0), D1.2 (A)
A1_PART2_LED: A1.20 (A1), D2.2 (A)
A3_PART3_LED: A1.21 (A2), D3.2 (A)
CS: A1.13 (D10), MOD1.CS
D8_PART4_LED: A1.11 (D8), D4.2 (A)
GND: A1.4 (GND), A1.29 (GND), C1.2, J1.2, J1.4, J2.8, MOD1.GND, R1.2, R2.1, R3.1, R4.1, R5.1, R6.1
MISO: A1.15 (D12), MOD1.MISO
MOSI: A1.14 (D11), MOD1.MOSI
unnamed: D1.1 (K), R2.2
unnamed: D2.1 (K), R3.2
unnamed: D3.1 (K), R4.2
unnamed: D4.1 (K), R5.2
unnamed: D5.1 (K), R6.2
PA3_EJECT_BUTTON: A1.22 (A3), R1.1, SW1.1
PA4_STATUS_LED: A1.23 (A4), D5.2 (A)
PA5: A1.24 (A5), J1.12, J2.9
PD2: A1.5 (D2), J1.15, J2.2
PD3: A1.6 (D3), J1.16, J2.3
PD4: A1.7 (D4), J1.17, J2.4
PD5: A1.8 (D5), J1.18, J2.5
PD6: A1.9 (D6), J1.3, J2.1
PD7: A1.10 (D7), J1.6, J2.6
SCK: A1.16 (D13), MOD1.SCK

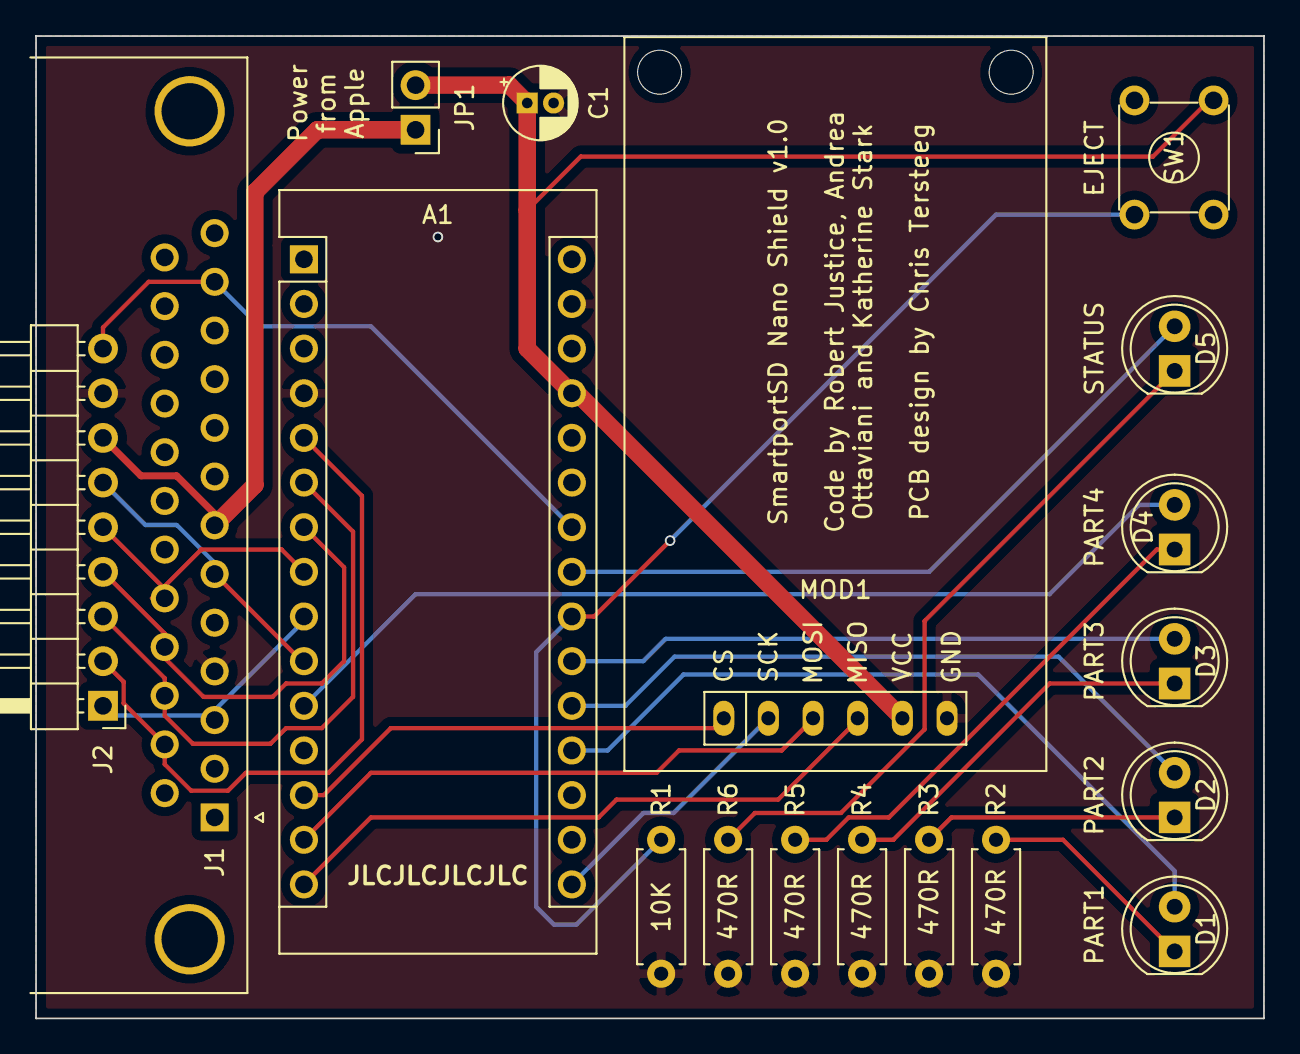
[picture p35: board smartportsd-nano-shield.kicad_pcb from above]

Board: 2 copper layers, 69.8 x 55.9 mm, 18 parts (0 on the bottom side), 25 nets.

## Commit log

2021-02-28 Initial version sent to JCL
    [smartportsd-nano-shield-B_Cu.gbr, smartportsd-nano-shield-B_Mask.gbr, smartportsd-nano-shield-B_SilkS.gbr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]
2021-03-31 Add some docs
    [smartportsd-nano-shield.sch]
2022-10-05 Add enclosure files
    [smartportsd body.stl, smartportsd button.stl, smartportsd lid.stl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]
2024-01-07 Restructure repo for multiple PCB projects
    [smartportsd body.stl, smartportsd button.stl, smartportsd lid.stl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]
2024-01-07 Add SMD V1.1 PCB
    [smartport-smd-body.stl, smartport-smd-button.stl, smartport-smd-db19.stl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]
2024-01-08 Initial round of updated docs for the SMD version
    [smartportsd-nano-shield-body.stl, smartportsd-nano-shield-button.stl, smartportsd-nano-shield-lid.stl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]
2024-01-08 Fix misnamed BOM file
    [bom-smd-v1.1.csv]
2025-03-01 Add IDC-20 pin mappings to docs
